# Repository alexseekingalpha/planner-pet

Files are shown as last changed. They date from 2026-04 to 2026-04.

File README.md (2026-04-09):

Planner Pet: By Alexander Smallwood
Welcome to my project - Planner pet! 
Inspired by my struggles with ADHD I wanted to mkae a deivce to motivate others and I to complete tasks regardless of what the task is. 
Take homework for example. Homework is so hard to complete as there is no instant reward, you must wait to finish the problem to recieve the dopamine of completing such homework. 
To fix this I hypothesise that a digital pet will create a bond to the user motivating them to complete tasks to keep the pet alive! Like a tamagotchi!

The process is simple and fun:
Complete tasks and your pet earns XP which lets it grow through life stages, and unlocks cosmetics. Miss tasks and it regresses eventually going dormant.
To enhance attachment, each pet is generated from a random seed so everyone has a unique pet!

Hardware:
MCU: Esp32-S3-Wroom-1-N8
Display: st7789 240x250 tft spi 
RTC: DS3231 
Power: 500mah lipo whith BQ24040 charging via USBC, TLV75801 ldo to regualate the power to the MCU
Input: 4 button dpad with + 2 standalone buttons for 'select' and 'back'
All KiCad files will be uploaded (Using KiCad 9)




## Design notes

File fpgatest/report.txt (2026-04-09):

Plotted to 'C:\Users\Alex\Downloads\fpgatest-F_Cu.gbr'.
Plotted to 'C:\Users\Alex\Downloads\fpgatest-B_Cu.gbr'.
Plotted to 'C:\Users\Alex\Downloads\fpgatest-F_Paste.gbr'.
Plotted to 'C:\Users\Alex\Downloads\fpgatest-B_Paste.gbr'.
Plotted to 'C:\Users\Alex\Downloads\fpgatest-F_Silkscreen.gbr'.
Plotted to 'C:\Users\Alex\Downloads\fpgatest-B_Silkscreen.gbr'.
Plotted to 'C:\Users\Alex\Downloads\fpgatest-F_Mask.gbr'.
Plotted to 'C:\Users\Alex\Downloads\fpgatest-B_Mask.gbr'.
Plotted to 'C:\Users\Alex\Downloads\fpgatest-Edge_Cuts.gbr'.
Created Gerber job file 'C:\Users\Alex\Downloads\fpgatest-job.gbrjob'.
Info: Done.
Plotted to 'C:\Users\Alex\Downloads\fpgatest-F_Cu.gbr'.
Plotted to 'C:\Users\Alex\Downloads\fpgatest-B_Cu.gbr'.
Plotted to 'C:\Users\Alex\Downloads\fpgatest-F_Paste.gbr'.
Plotted to 'C:\Users\Alex\Downloads\fpgatest-B_Paste.gbr'.
Plotted to 'C:\Users\Alex\Downloads\fpgatest-F_Silkscreen.gbr'.
Plotted to 'C:\Users\Alex\Downloads\fpgatest-B_Silkscreen.gbr'.
Plotted to 'C:\Users\Alex\Downloads\fpgatest-F_Mask.gbr'.
Plotted to 'C:\Users\Alex\Downloads\fpgatest-B_Mask.gbr'.
Plotted to 'C:\Users\Alex\Downloads\fpgatest-Edge_Cuts.gbr'.
Created Gerber job file 'C:\Users\Alex\Downloads\fpgatest-job.gbrjob'.
Info: Done.
Info: Done.
Info: Done.

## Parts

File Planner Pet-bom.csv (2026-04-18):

Name | Purpose | Quantity | Total Cost (USD) | Link | Distributor
1k Resistor 0603 | LED current limiting (R5,R6,R7) | 3 | 0.03 | https://www.lcsc.com/product-detail/C21190.html | LCSC
10k Resistor 0603 | Pulldown / pullup (R1,R10) | 2 | 0.03 | https://www.lcsc.com/product-detail/C25804.html | LCSC
5.1k Resistor 0603 | USB CC pulldown (R8,R9) | 2 | 0.03 | https://www.lcsc.com/product-detail/C23186.html | LCSC
2k Resistor 0603 | BQ24040 charge current set (R4) | 1 | 0.03 | https://www.lcsc.com/product-detail/C22975.html | LCSC
100k Resistor 0603 | LDO feedback divider (R3) | 1 | 0.03 | https://www.lcsc.com/product-detail/C25803.html | LCSC
560k Resistor 0603 | LDO feedback divider (R2) | 1 | 0.03 | https://www.lcsc.com/product-detail/C23203.html | LCSC
1uF Capacitor 0603 | Decoupling / bypass (C1-C5) | 5 | 0.15 | https://www.lcsc.com/product-detail/C15849.html | LCSC
100nF Capacitor 0603 | Decoupling (C6,C8,C9) | 3 | 0.06 | https://www.lcsc.com/product-detail/C14663.html | LCSC
10uF Capacitor 0603 | LDO output capacitor (C7) | 1 | 0.16 | https://www.lcsc.com/product-detail/C19702.html | LCSC
Red LED 0603 (150060RS75000) | Charge status indicator (D1) | 1 | 1.34 | https://www.lcsc.com/product-detail/C3030991.html | LCSC
Green LED 0603 (150060GS75000) | Power good indicator (D2) | 1 | 1.40 | https://www.lcsc.com/product-detail/C5252984.html | LCSC
Blue LED 0603 (150060BS75000) | General indicator (D3) | 1 | 1.12 | https://www.lcsc.com/product-detail/C5197644.html | LCSC
ESP32-S3-WROOM-1-N16R8 | Main MCU - WiFi/BLE SoC (U4) | 1 | 10.38 | https://www.lcsc.com/product-detail/C2913202.html | LCSC
BQ24040DSQR | Li-ion battery charger IC (U2) | 1 | 2.05 | https://www.lcsc.com/product-detail/C81080.html | LCSC
USBLC6-2SC6 | USB ESD protection (U1) | 1 | 0.77 | https://www.lcsc.com/product-detail/C7519.html | LCSC
TLV75801PDBVR | 3.3V LDO regulator (U3) | 1 | 0.56 | https://www.lcsc.com/product-detail/C2877852.html | LCSC
2N7002 | Buzzer MOSFET driver (Q1) | 1 | 0.13 | https://www.lcsc.com/product-detail/C8545.html | LCSC
PKLCS1212E4001-R1 | Passive piezo buzzer (LS1) | 1 | 1.54 | https://www.lcsc.com/product-detail/C113159.html | LCSC
KMR211GLFS | Tactile switches - navigation + boot/reset | 8 | 8.32 | https://www.lcsc.com/product-detail/C221675.html | LCSC
PCM12SMTR | Power slide switch (SW1) | 1 | 2.36 | https://www.lcsc.com/product-detail/C221841.html | LCSC
USB4105-GF-A | USB-C receptacle 16pin (J1) | 1 | 0.20 | https://www.lcsc.com/product-detail/C2765186.html | LCSC
B2B-PH-K-S(LF)(SN) | JST PH 2-pin battery connector (J5) | 1 | 0.10 | https://www.lcsc.com/product-detail/C131337.html | LCSC
KH-2.54FH-1X8P-H8.5 | 1x8 female header for screen (J4) | 1 | 0.21 | https://www.lcsc.com/product-detail/C2905417.html | LCSC
KH-2.54PH180-1X5P-L11.5 | 1x5 male header for RTC (J3) | 1 | 0.08 | https://www.lcsc.com/product-detail/C2932699.html | LCSC

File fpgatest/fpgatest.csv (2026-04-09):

Id | Designator | Footprint | Quantity | Designation | Supplier and ref
1 | D3,D1,D2 | LED_0603_1608Metric | 3 | LED
2 | R7,R5,R6 | R_0603_1608Metric | 3 | 1k
3 | reset1,BTN_DOWN1,BTN_RIGHT1,boot1,BTN_BACK1,BTN_Select1,BTN_LEFT1,BTN_UP1 | SW_Push_1P1T_NO_CK_KMR2 | 8 | SW_Push
4 | U4 | ESP32-S3-WROOM-1 | 1 | ESP32-S3-WROOM-1
5 | R10,R1 | R_0603_1608Metric | 2 | 10k
6 | Q1 | SOT-23 | 1 | 2N7002
7 | LS1 | SPKR_PKLCS1212E4001-R1 | 1 | PKLCS1212E4001-R1
8 | SW1 | SW_SPDT_PCM12 | 1 | SW_SPST
9 | C3,C4,C5,C2,C1 | C_0603_1608Metric | 5 | 1uF
10 | R2 | R_0603_1608Metric | 1 | 560k
11 | J4 | PinSocket_1x08_P2.54mm_Vertical | 1 | screen female header
12 | C9,C8,C6 | C_0603_1608Metric | 3 | 0.1uF
13 | R9,R8 | R_0603_1608Metric | 2 | 5.1k
14 | R4 | R_0603_1608Metric | 1 | 2k
15 | U3 | SOT95P280X145-5N | 1 | TLV75801PDBVR
16 | R3 | R_0603_1608Metric | 1 | 100k
17 | C7 | C_0603_1608Metric | 1 | 10uF
18 | J5 | JST_B2B-PH-K-S | 1 | B2B-PH-K-S
19 | U1 | SOT-23-6 | 1 | USBLC6-2SC6
20 | U2 | SON40P200X200X80-11N | 1 | BQ24040DSQR
21 | J3 | PinHeader_1x05_P2.54mm_Vertical | 1 | real time clock male header
22 | J1 | USB_C_Receptacle_GCT_USB4105-xx-A_16P_TopMnt_Horizontal | 1 | USB_C_Receptacle_USB2.0_16P

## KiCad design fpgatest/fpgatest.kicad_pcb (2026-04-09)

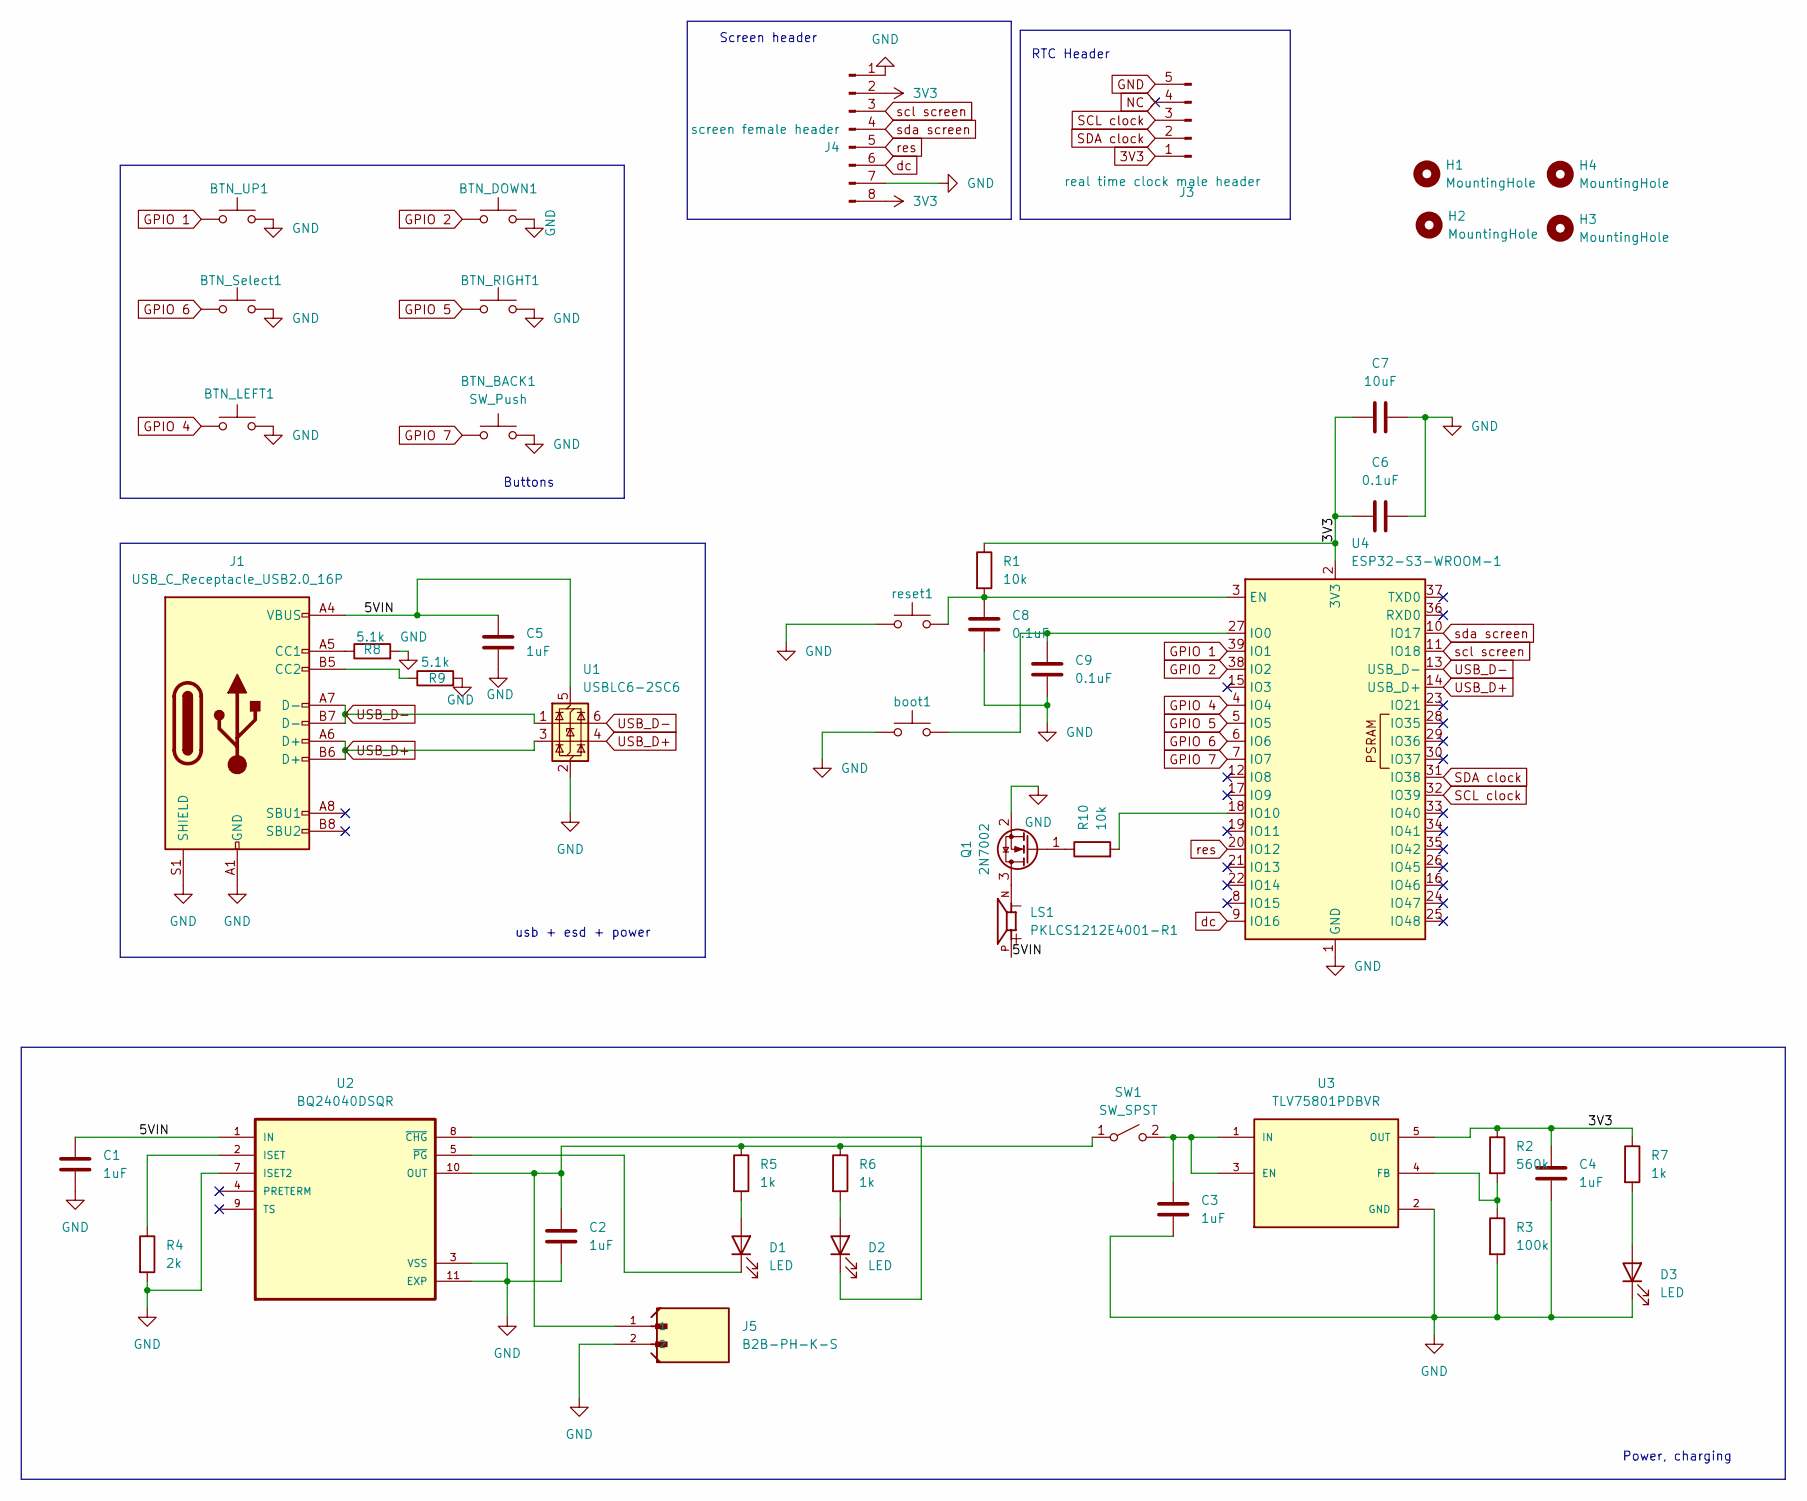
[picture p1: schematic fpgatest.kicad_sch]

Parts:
BTN_BACK1: SW_Push; SW_Push_1P1T_NO_CK_KMR2
BTN_DOWN1: SW_Push; SW_Push_1P1T_NO_CK_KMR2
BTN_LEFT1: SW_Push; SW_Push_1P1T_NO_CK_KMR2
BTN_RIGHT1: SW_Push; SW_Push_1P1T_NO_CK_KMR2
BTN_Select1: SW_Push; SW_Push_1P1T_NO_CK_KMR2
BTN_UP1: SW_Push; SW_Push_1P1T_NO_CK_KMR2
C1, C2, C3, C4, C5: 1uF; C_0603_1608Metric
C6, C8, C9: 0.1uF; C_0603_1608Metric
C7: 10uF; C_0603_1608Metric
D1, D2, D3: LED; LED_0603_1608Metric
H1, H2, H3, H4: MountingHole; MountingHole_2.2mm_M2
J1: USB_C_Receptacle_USB2.0_16P; USB_C_Receptacle_GCT_USB4105-xx-A_16P_TopMnt_Horizontal
J3: real time clock male header; PinHeader_1x05_P2.54mm_Vertical
J4: screen female header; PinSocket_1x08_P2.54mm_Vertical
J5: B2B-PH-K-S; JST_B2B-PH-K-S
LS1: PKLCS1212E4001-R1; SPKR_PKLCS1212E4001-R1; PARTREV January 22, 2018
Q1: 2N7002; SOT-23
R1, R10: 10k; R_0603_1608Metric
R2: 560k; R_0603_1608Metric
R3: 100k; R_0603_1608Metric
R4: 2k; R_0603_1608Metric
R5, R6, R7: 1k; R_0603_1608Metric
R8, R9: 5.1k; R_0603_1608Metric
SW1: SW_SPST; SW_SPDT_PCM12
U1: USBLC6-2SC6; SOT-23-6
U2: BQ24040DSQR; SON40P200X200X80-11N
U3: TLV75801PDBVR; SOT95P280X145-5N; PARTREV D
U4: ESP32-S3-WROOM-1
boot1: SW_Push; SW_Push_1P1T_NO_CK_KMR2
reset1: SW_Push; SW_Push_1P1T_NO_CK_KMR2

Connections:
3V3: C4.1, C6.1, C7.1, J3.1, J4.2, J4.8, R1.1, R2.1, R7.1, U3.5 (OUT), U4.2 (3V3)
/5VIN: C1.1, C5.1, J1.A4 (VBUS), J1.A9 (VBUS), J1.B4 (VBUS), J1.B9 (VBUS), LS1.P, U1.5 (VBUS), U2.1 (IN)
GND: BTN_BACK1.2, BTN_DOWN1.2, BTN_LEFT1.2, BTN_RIGHT1.2, BTN_Select1.2, BTN_UP1.2, C1.2, C2.2, C3.2, C4.2, C5.2, C6.2, C7.2, C8.2, C9.2, D3.1 (K), J1.A1 (GND), J1.A12 (GND), J1.B1 (GND), J1.B12 (GND), J1.S1 (SHIELD), J3.5, J4.1, J4.7, J5.2, Q1.2 (S), R3.2, R4.2, R8.2, R9.2, U1.2 (GND), U2.3 (VSS), U2.7 (ISET2), U2.11 (EXP), U3.2 (GND), U4.1 (GND), U4.40 (GND), U4.41 (GND), boot1.1, reset1.1
GPIO 1: BTN_UP1.1, U4.39 (IO1)
GPIO 2: BTN_DOWN1.1, U4.38 (IO2)
GPIO 4: BTN_LEFT1.1, U4.4 (IO4)
GPIO 5: BTN_RIGHT1.1, U4.5 (IO5)
GPIO 6: BTN_Select1.1, U4.6 (IO6)
GPIO 7: BTN_BACK1.1, U4.7 (IO7)
NC: J3.4
unnamed: D1.2 (A), R5.2
unnamed: D1.1 (K), U2.5 (~PG)
unnamed: D2.2 (A), R6.2
unnamed: D2.1 (K), U2.8 (~CHG)
unnamed: D3.2 (A), R7.2
unnamed: J1.A5 (CC1), R8.1
unnamed: J1.B5 (CC2), R9.1
unnamed: LS1.N, Q1.3 (D)
unnamed: Q1.1 (G), R10.1
unnamed: C2.1, J5.1, R5.1, R6.1, SW1.1 (A), U2.10 (OUT)
unnamed: C3.1, SW1.2 (B), U3.1 (IN), U3.3 (EN)
unnamed: R4.1, U2.2 (ISET)
unnamed: R2.2, R3.1, U3.4 (FB)
unnamed: C8.1, R1.2, U4.3 (EN), reset1.2
unnamed: C9.1, U4.27 (IO0), boot1.2
unnamed: R10.2, U4.18 (IO10)
SCL clock: J3.3, U4.32 (IO39)
SDA clock: J3.2, U4.31 (IO38)
USB_D+: J1.A6 (D+), J1.B6 (D+), U1.3 (I/O2), U1.4 (I/O2), U4.14 (USB_D+)
USB_D-: J1.A7 (D-), J1.B7 (D-), U1.1 (I/O1), U1.6 (I/O1), U4.13 (USB_D-)
dc: J4.6, U4.9 (IO16)
res: J4.5, U4.20 (IO12)
scl screen: J4.3, U4.11 (IO18)
sda screen: J4.4, U4.10 (IO17)

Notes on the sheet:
Screen header
Buttons
RTC Header
Power, charging
usb + esd + power

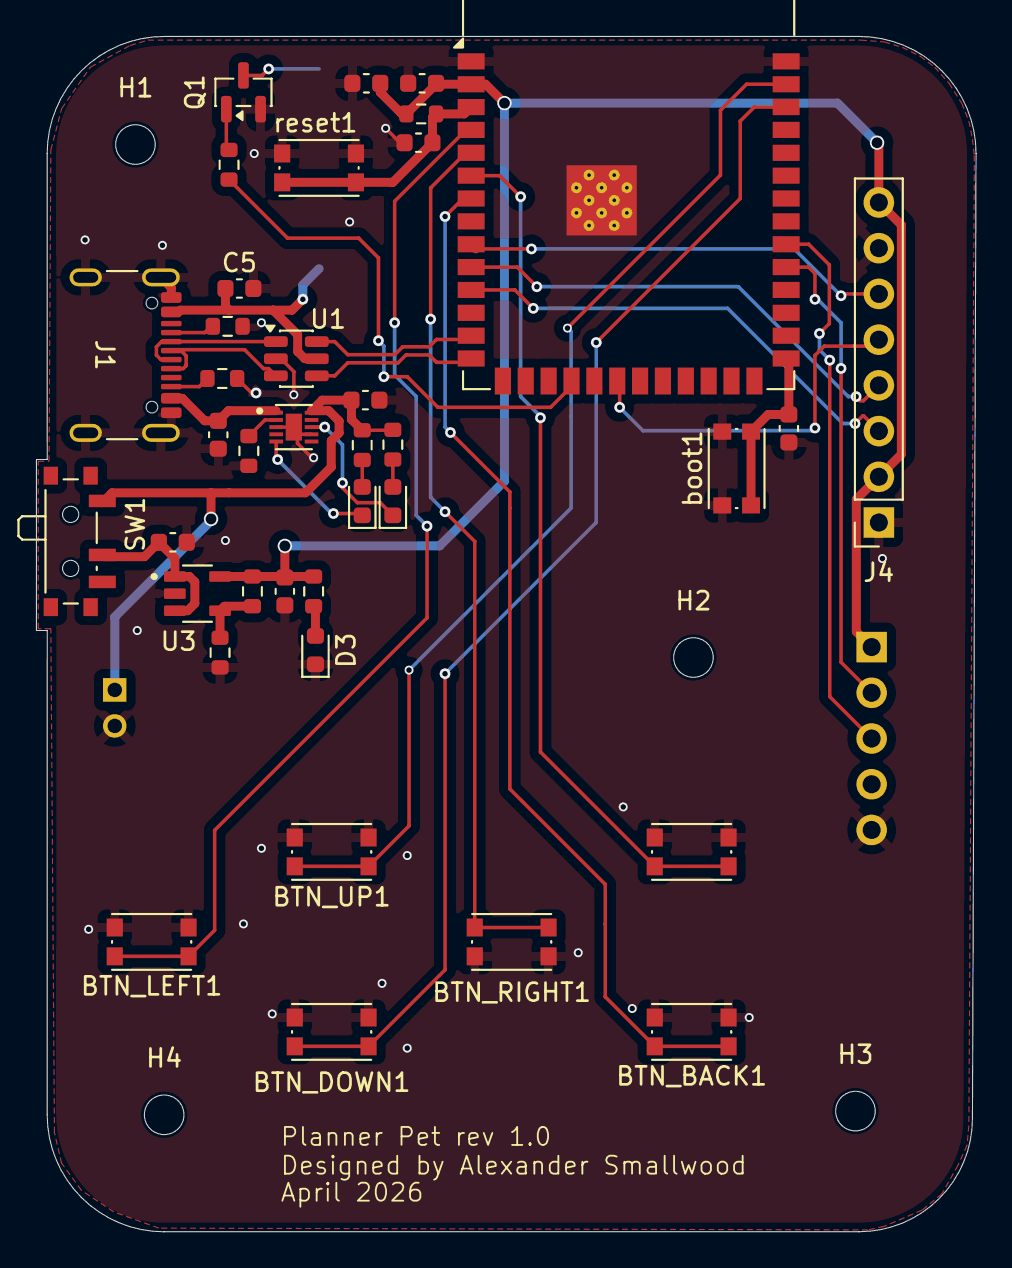
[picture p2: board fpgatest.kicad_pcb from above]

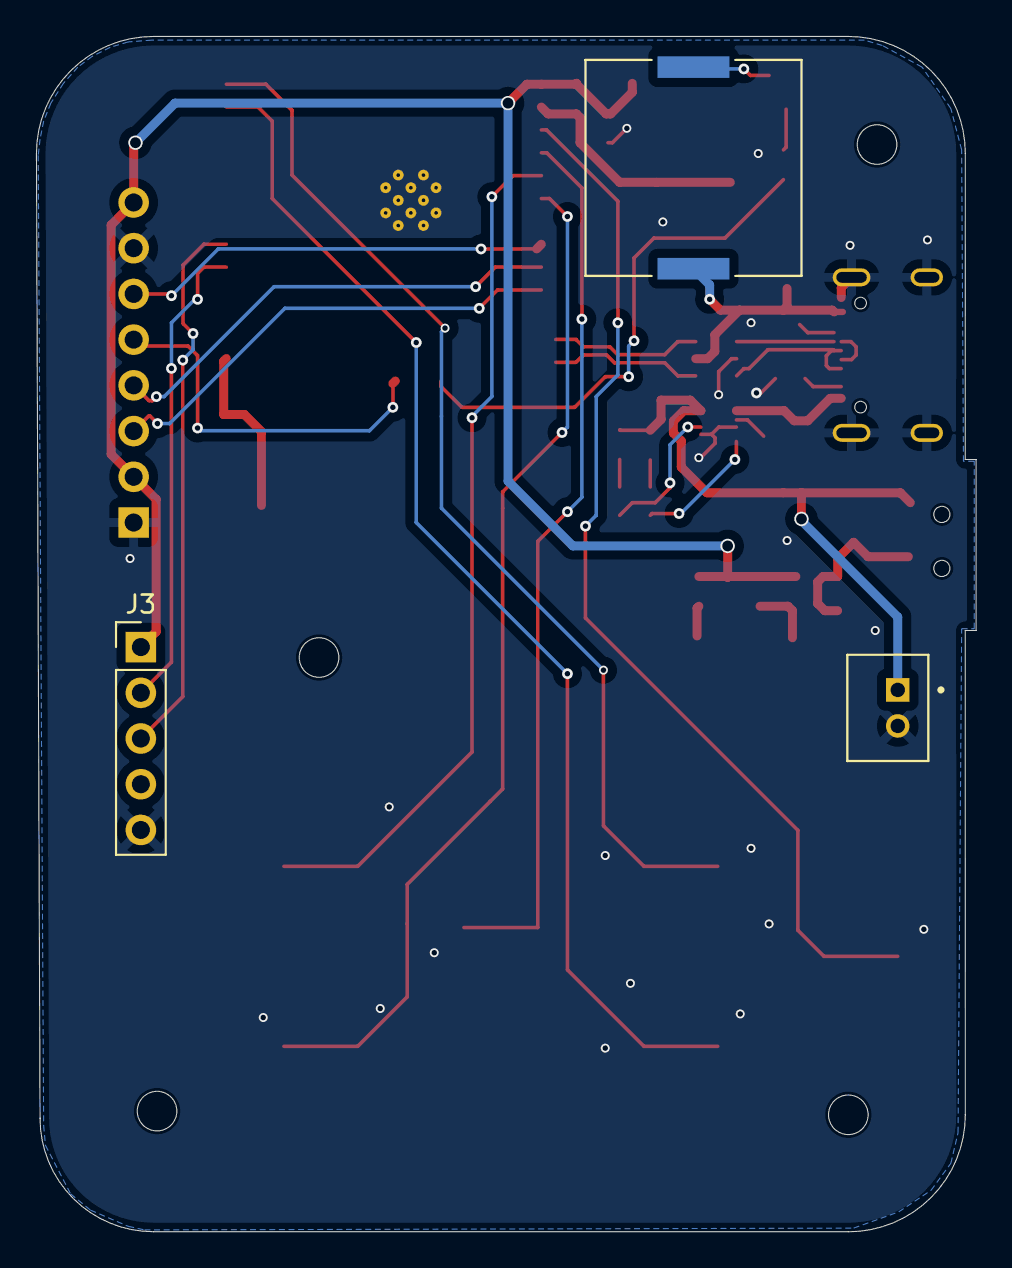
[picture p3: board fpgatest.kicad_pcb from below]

Board: 2 copper layers, 52.2 x 66.4 mm, 45 parts (3 on the bottom side), 33 nets.

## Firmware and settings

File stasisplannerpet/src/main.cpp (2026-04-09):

#include <Arduino.h>


const char* STAGES[] = {"Egg", "Baby", "Kid", "Teen", "Adult", "Elder"};
const int XP_THRESHOLDS[] = {0, 10, 30, 60, 100, 150};
const int NUM_STAGES = 6;

const char* STAGE_ART[] = {
    "  (.)  ",    // Egg
    " (^_^) ",    // Baby
    " (^o^) ",    // Kid
    "<(^_^)>",    // Teen
    "<(^O^)>",    // Adult
    "*<(^O^)>*"   // Elder
};

// Pet 
struct Pet {
    int seed;
    String name;
    int bodyShape;    
    int colourIndex;  
    int personality;  
    int xp;
    int coins;
    int missStreak;
};

// Tasks
struct Task {
    String name;
    int duration;     
    bool completed;
};

//  Globals
Pet pet;
Task tasks[10];       
int taskCount = 0;

//Helpers

String readLine() {
    while (!Serial.available()) {
        delay(10);
    }
    String input = Serial.readStringUntil('\n');
    input.trim();
    return input;
}


int readInt() {
    String line = readLine();
    return line.toInt();
}


void generateTraits() {
    pet.bodyShape   = pet.seed % 3;
    pet.colourIndex = pet.seed % 8;
    pet.personality = (pet.seed / 1000) % 3;
}


int getStage(int xp) {
    for (int i = NUM_STAGES - 1; i >= 0; i--) {
        if (xp >= XP_THRESHOLDS[i]) return i;
    }
    return 0;
}


void showPet() {
    int stage = getStage(pet.xp);
    const char* bodies[] = {"Round", "Tall", "Chunky"};
    const char* personalities[] = {"Calm", "Hyper", "Sleepy"};

    Serial.println();
    Serial.println("====== " + pet.name + " ======");
    Serial.print("     ");
    Serial.println(STAGE_ART[stage]);
    Serial.println("  Stage: " + String(STAGES[stage]));
    Serial.println("  XP: " + String(pet.xp) + "  Coins: " + String(pet.coins));
    Serial.println("  Body: " + String(bodies[pet.bodyShape]) +
                   "  Personality: " + String(personalities[pet.personality]));
    if (pet.missStreak > 0) {
        Serial.println("  Miss streak: " + String(pet.missStreak) + " (pet is sad!)");
    }
    Serial.println("========================");
}


void addTask() {
    if (taskCount >= 10) {
        Serial.println("Task list full! End the day first.");
        return;
    }

    Serial.print("Task name: ");
    tasks[taskCount].name = readLine();

    Serial.print("Duration (minutes): ");
    tasks[taskCount].duration = readInt();
    tasks[taskCount].completed = false;
    taskCount++;

    Serial.println("Task added!");
}

void doTasks() {
    if (taskCount == 0) {
        Serial.println("No tasks! Add some first.");
        return;
    }

    Serial.println("\n--- Today's Tasks ---");
    for (int i = 0; i < taskCount; i++) {
        Serial.print(String(i + 1) + ". [");
        Serial.print(tasks[i].completed ? "X" : " ");
        Serial.println("] " + tasks[i].name + " (" + String(tasks[i].duration) + " min)");
    }

    Serial.print("Complete which task? (0 to cancel): ");
    int choice = readInt();

    if (choice < 1 || choice > taskCount) return;

    Task &t = tasks[choice - 1];
    if (t.completed) {
        Serial.println("Already done!");
        return;
    }

    t.completed = true;
    int xpGain = 5 + t.duration / 10;
    int coinGain = 2 + t.duration / 15;

    int oldStage = getStage(pet.xp);
    pet.xp += xpGain;
    pet.coins += coinGain;
    pet.missStreak = 0;
    int newStage = getStage(pet.xp);

    Serial.println("Done! +" + String(xpGain) + " XP, +" + String(coinGain) + " coins");
    if (newStage > oldStage) {
        Serial.println("*** " + pet.name + " grew into " + String(STAGES[newStage]) + "! ***");
    }
}

void endOfDay() {
    int missed = 0;
    int penalty = 0;

    for (int i = 0; i < taskCount; i++) {
        if (!tasks[i].completed) {
            missed++;
            penalty += 100 / max(tasks[i].duration, 1);
        }
    }

    if (missed == 0) {
        Serial.println("\nAll tasks done today! " + pet.name + " is happy!");
    } else {
        pet.missStreak += missed;
        pet.xp = max(0, pet.xp - penalty);
        Serial.println("\nMissed " + String(missed) + " task(s). -" +
                       String(penalty) + " XP. " + pet.name + " is sad...");
    }

    // Clear tasks for next day
    taskCount = 0;
}

//  Menu 

void showMenu() {
    Serial.println("\n1. Add task");
    Serial.println("2. Do tasks");
    Serial.println("3. End day");
    Serial.print("> ");
}

// 

void setup() {
    Serial.begin(115200);
    delay(1000);

    Serial.println("=== PLANNER PET ===");
    Serial.print("Name your pet: ");
    pet.name = readLine();

    
    randomSeed(analogRead(0) ^ millis());
    pet.seed = random(0, 100000);
    pet.xp = 0;
    pet.coins = 0;
    pet.missStreak = 0;
    generateTraits();

    Serial.println(pet.name + " hatched! (Seed: " + String(pet.seed) + ")");
}

void loop() {
    showPet();
    showMenu();

    int choice = readInt();

    switch (choice) {
        case 1: addTask(); break;
        case 2: doTasks(); break;
        case 3: endOfDay(); break;
        default: Serial.println("Pick 1-3."); break;
    }
}

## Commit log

2026-04-09 Code for the planner pet!
    A good prototype code for the planner pet!
2026-04-09 Add files via upload
    Keep in mind the files are called "fpgatest" as this project started as that but I switched to this project but used the same kicad file on accident, can change in the future if its an issue
    [fpgatest.csv, fpgatest.kicad_pcb, fpgatest.kicad_sch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]
